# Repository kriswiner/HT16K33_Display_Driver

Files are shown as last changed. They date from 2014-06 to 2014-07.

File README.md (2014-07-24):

HT16K33_Display_Driver
======================

Simple demo of driving 4, four-digit, seven-segment [HP QDSP-6064 bubble displays](https://www.sparkfun.com/products/12710) with one [HT16K33 display driver](http://www.adafruit.com/datasheets/ht16K33v110.pdf)

Each HT16K33 cathode pin can drive two display cathodes. The HT16K33 has eight cathode pins and 16 anode pins. Therefore, the RAM Mapping HT16K33 can drive a total of 128 LED segments. So a total of four, 4-digit, 7-segment displays can be driven with this one chip with just 2 TWI wires and power and ground. That is a lot of display without taking up a lot of the GPIO pins.

I decided to try to reduce this idea of driving four bubble displays to practice; what follows is what I did and how it worked out.

First I breadboarded the circuit with Adafruit's [HT16K33 breakout board] (http://www.adafruit.com/products/1427) shown here:
 


Here is what my initial circuit looked like. The HT16K33 is powered by the 3.3 V reference from and connected to the I2C of an 8 MHz Pro Mini Arduino microcontroller.



I was able to easily get two bubble displays running from the HT16K33 breakout on my little breadboard. I actually added a third display using jumper wires to another breadboard just to prove that I really could drive four (well, at least three!) of the bubble displays at a time with just one HT16K33.

After that success, I spent most of a Saturday soldering up a circuit on a perf board with four bubble displays and one HT16K33. This is what it looks like:



Look at all those wires! This is not a great picture but you can see that all four displays are working using the display driver sketch in this repository, which currently displays floating point (top left and bottom right) or integer (top right and bottom left) numbers of four digits or less. The sketch has simple utility but is good enough to display temperature, time, and other sensor output.

The last step was biting the bullet and learning how to use Eagle CAD to design a PCB with the same circuit. It took only a few days mostly because: 1) I was able to take advantage of all the work Adafruit and [uChip](https://github.com/uChip/BubbleDisplay) had already done and, 2) I got a lot of help from Jim Lindblom of [Sparkfun] (http://www.sparkfun.com) and Dan Sheadel of [OSHPark] (http://www.oshpark.com), where I am having the first prototypes made. Here is what the boards will look like at almost actual size! (1.48 x 1.58 inches).

..........

I received the boards from OSHPark and promptly put the components on. A bad picture of the board is shown above. It was straightforward to solder even the small diode; 0805 passive components are easy to handle with a good pair of tweezers. Using a soldering iron for surface mounted components is doable but the solder joints are never going to look like machine-made parts do without a lot of practice. I noticed that the displays worked just fine mounted in their through holes before soldering; I guess there is enough contact to allow the proper current flow even without soldering. I assembled all three boards and---they all worked! I love it when this happens. This is what the boards look like in action.



The board is connected to an Arduino 3.3 V 8 MHz Pro Mini running the sketch in this repository. Notice that there are only four wires, not the rat's nest of wires from the perf board prototype. So what are the advantages of this "FrontPack" design over conventional LED display choices?  Well, 1) you don't need external current-limiting resistors with the HT16K33 chip, 2) you can run the display board wih 3.3 V or 5 V as you wish, 3) it only takes four wires to control up to 8 x 4 four-digit displays since up to eight of these "FrontPacks" can be independently addressed in a given circuit by soldering a unique 3-bit address on the board pads, 4) it has a rather small footprint at 1.48 x 1.58 inches square so it saves space, and 5) it is so retro cool!

This is the first prototype; there are several variants I can think of that might be more useful for a given application. For example, why not mount the HT16K33 on the back to make a conventional "BackPack" version of this display. This would come in handy for mounting on a cased surface. The FrontPack (I'll toss the scare quotes from now on) has the additional attribute that the bubble displays, even fully inserted into the through holes, stand proud of the top surface of the HT16K33 chip, meaning that even the FrontPack can be mounted, albeit a little more awkwardly, on an inner case surface with only the displays visible outside. But the really neat thing about the bubble displays and this through-hole mounting is that the displays can be soldered into the board at a tilt angle to aid viewing and can stand as much as a millimeter prouder still of the HT16K33 chip by a judicious choice of how far to push the displays into the board before soldering. Bottom line: even the FrontPack is likely to suit most needs.

Now there is a quirk with the current setup (there always is!). I noticed a curious unwanted behavior with this driver chip. The sketch works as intended when I have the displays numbered in (the somewhat unintuitive) order 1-2-3-4 from top right to bottom left. When I change the order to go from top left to bottom right (the more intuitive ordering), everything still works but the minus sign on displays 1 and 3 becomes intermittent. I don’t understand this behavior yet, but I suspect it has something to do with the RAM ordering of the multiplexing coupled with the particular way I am constructing the characters to display.  That is, I am hoping it is a subtle software error and not some hidden limitation of the chip. It doesn’t get in the way of using any or all of the displays, but in the interest of full disclosure, I thought I would mention this oddity. If anyone spots my error in the sketch above I would appreciate a heads up.

This is version v.01 and there are a few things I would do differently. I noticed that Adafruit (from whom I shamelessly copied the idea of using the HT16K33) used a 24 mil trace for their VDD and GND lines. This is good practice that I would follow next time but didn't here. Likewise, putting the capacitor right next to ground is OK, but it might be better to place it right next to the VDD pin on the HT16K33, instead. I used 4.7 kOhm resistors as pull-ups for the SDA and SCL lines since I am currently in the habit of using fast (400 kHz) I2C. This is in contrast to the 10 kOhm pullups used by Adafruit. I'd stick with the 4.7 kOhm in the next design iteration. Lastly, I used 39 kOhm resistors in the address lines as specified in the HT16K33 data sheet instead of the 47 kOhm resistors used by Adafruit. They probably just had a lot of these 47 kOhm resistors lying around.

I had a lot of fun designing this board, my first real experience with Eagle CAD, and I must close by thanking Adafruit for showiing me how to use this wonderful chip by Holtek, uChip from whom I shamelessly borrowed the QDSP-6064 Eagle device package and who has devised a different solution to using these retro cool bubble displays, and Sparkfun Electronics for their cheery answers to all my inane questions, and somehow providing an inexpensive supply of these quirky, odd looking, lovable bubble displays.

Despite standing on the shoulders of these giants, I take full responsibility for any and all errors in the sketch or Eagle design. I would only ask that you tell me when you find an error so I can do my best to fix it.

Update: Well I think I figured out the display ordering problem. In some sense I organized the displays backward. I think the HT16K33 prefers to roll through the RAM map sequentially and if I try to display out of order the chip has a harder time with the multiplexing. This is probably a direct result of my copying Adafruit's and uChip's schematics which were arranged for "backpack" displays, not the "frontpack" design I am using. I can still get any display or all the displays to function correctly, but it's somewhat annoying to have the top right display be number one  and then go top right to top left, then bottom right to bottom left instead of the more intuitive top left to top right, bottom left to bottom right ordering. The proper way to use this chip is to display to C0-3 A0-7, then C4-7 A0-7, then C0-3 A8-15, and finally C4-7 A8-15, I think. In any case, I took the opportunity to "fix" the design by swapping the top left bubble display with the top right one, etc., in a version 2 of the design. I also reduced the size of the board by 6% by avoiding setting traces outside, on the far side, of the bubble displays. Adafruit used 24 mil traces for their power and ground, so that's what I am using in the new design. I was using 10 mil traces everywhere else in version 1 and I maintained that in version 2. Finally, I shrunk the vias down to 15 mil diameter so I won't have gigantic holes all over the board. I ordered three boards from OSH Park and when they arrive and I assemble and test the new version, I will report the results. Here is what the new boards will look like:

....

I got the boards assembled and tested and they look pretty good! They are a little smaller than the first version, don't have that annoying display order problem, and have a slightly more rational trace pattern as well as thicker traces for power and ground. Here are a few photos:

    

The display is showing data from the BMP-180 pressure sensor. Top left is temperature in degrees Fahrenheit, top right is pressure in kiloPascals, bottom right is elevation in feet and bottom left in meters. This is a very convenient way to display numerical data. It's not as much information as can be displayed on a 16 x 2 LCD or 48 x 84 Nokia 5110 LCD display, both of which I use and love, but it only requires four wires compared to the seven or eight for the other displays. And of course, the bubble display is way retro cooler, too!

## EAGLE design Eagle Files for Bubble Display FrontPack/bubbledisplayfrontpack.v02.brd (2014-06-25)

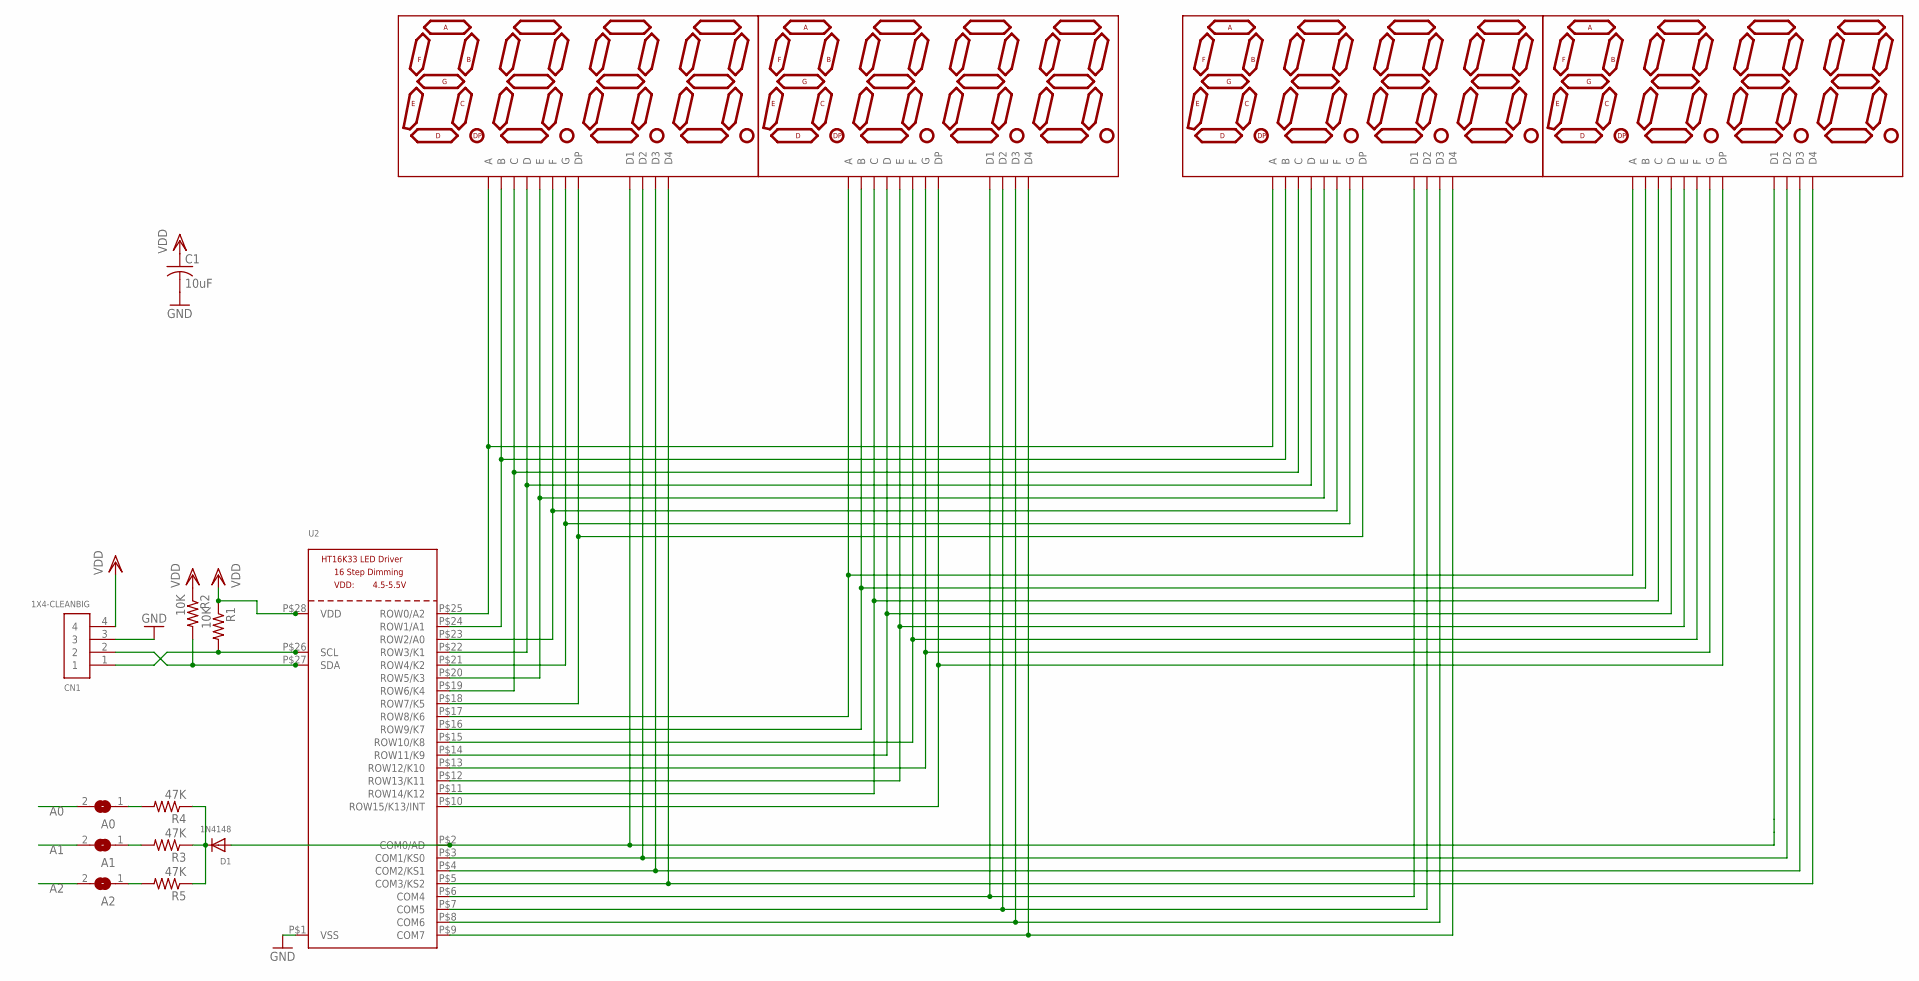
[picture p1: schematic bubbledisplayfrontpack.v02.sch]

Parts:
A0, A1, A2: SOLDERJUMPERREFLOW_NOPASTE; SOLDERJUMPER_REFLOW_NOPASTE
C1: 10uF; C0805K
CN1: 1X4-CLEANBIG; 1X04-CLEANBIG
D1: 1N4148; SOD-323F
DISPLAY1, DISPLAY2, DISPLAY3, DISPLAY4: hp; DIL12
R1, R2: 10K; R0805
R3, R4, R5: 47K; R0805
U2: HT16K33_SOP28; SOP28_300MIL

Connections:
A0: A0.2, DISPLAY1.9 (F), DISPLAY3.9 (F), U2.P$23 (ROW2/A0)
A1: A1.2, DISPLAY1.11 (B), DISPLAY3.11 (B), U2.P$24 (ROW1/A1)
A2: A2.2, DISPLAY1.12 (A), DISPLAY3.12 (A), U2.P$25 (ROW0/A2)
C0P1: D1.A, DISPLAY2.1 (D1), DISPLAY3.1 (D1), U2.P$2 (COM0/AD)
C1P10: DISPLAY2.10 (D2), DISPLAY3.10 (D2), U2.P$3 (COM1/KS0)
C2P4: DISPLAY2.4 (D3), DISPLAY3.4 (D3), U2.P$4 (COM2/KS1)
C3P6: DISPLAY2.6 (D4), DISPLAY3.6 (D4), U2.P$5 (COM3/KS2)
C4P1: DISPLAY1.1 (D1), DISPLAY4.1 (D1), U2.P$6 (COM4)
C5P10: DISPLAY1.10 (D2), DISPLAY4.10 (D2), U2.P$7 (COM5)
C6P4: DISPLAY1.4 (D3), DISPLAY4.4 (D3), U2.P$8 (COM6)
C7P6: DISPLAY1.6 (D4), DISPLAY4.6 (D4), U2.P$9 (COM7)
GND: C1.2, CN1.3, U2.P$1 (VSS)
unnamed: D1.C, R3.1, R4.1, R5.1
unnamed: DISPLAY1.8 (D), DISPLAY3.8 (D), U2.P$22 (ROW3/K1)
unnamed: DISPLAY2.9 (F), DISPLAY4.9 (F), U2.P$15 (ROW10/K8)
unnamed: A2.1, R5.2
unnamed: DISPLAY2.2 (E), DISPLAY4.2 (E), U2.P$12 (ROW13/K11)
unnamed: A1.1, R3.2
unnamed: A0.1, R4.2
SCL: CN1.1, R1.2, U2.P$26 (SCL)
SDA: CN1.2, R2.2, U2.P$27 (SDA)
SEGAD24P12: DISPLAY2.12 (A), DISPLAY4.12 (A), U2.P$17 (ROW8/K6)
SEGBD24P11: DISPLAY2.11 (B), DISPLAY4.11 (B), U2.P$16 (ROW9/K7)
SEGCP3: DISPLAY2.3 (C), DISPLAY4.3 (C), U2.P$11 (ROW14/K12)
SEGD13EP2: DISPLAY1.7 (G), DISPLAY3.7 (G), U2.P$21 (ROW4/K2)
SEGD13GP7: DISPLAY1.3 (C), DISPLAY3.3 (C), U2.P$19 (ROW6/K4)
SEGDD24P8: DISPLAY2.8 (D), DISPLAY4.8 (D), U2.P$14 (ROW11/K9)
SEGDPD13P5: DISPLAY1.5 (DP), DISPLAY3.5 (DP), U2.P$18 (ROW7/K5)
SEGDPP5: DISPLAY2.5 (DP), DISPLAY4.5 (DP), U2.P$10 (ROW15/K13/INT)
SEGED13P2: DISPLAY1.2 (E), DISPLAY3.2 (E), U2.P$20 (ROW5/K3)
SEGFP9: DISPLAY2.7 (G), DISPLAY4.7 (G), U2.P$13 (ROW12/K10)
VDD: C1.1, CN1.4, R1.1, R2.1, U2.P$28 (VDD)

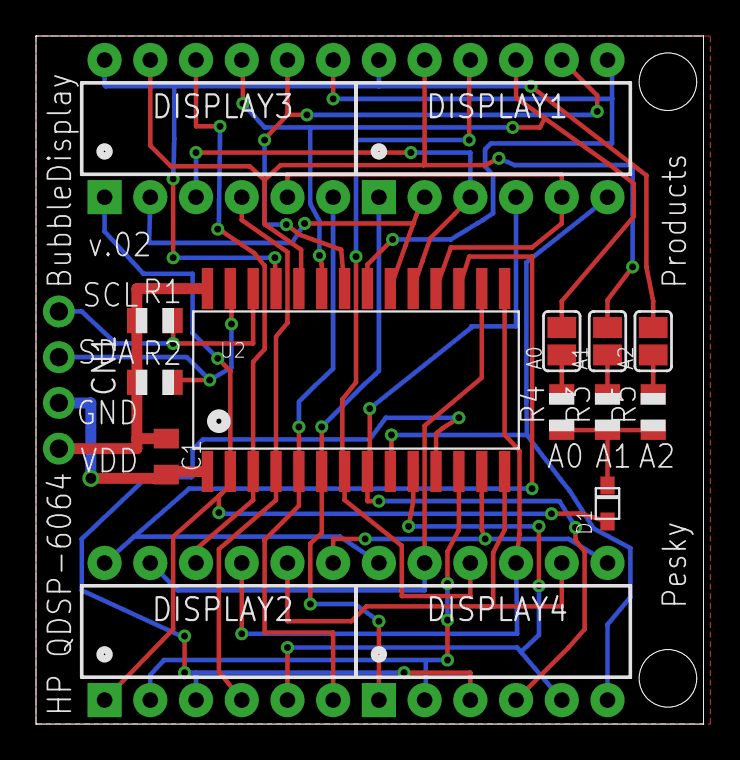
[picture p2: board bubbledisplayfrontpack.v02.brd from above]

Board: 2 copper layers, 37.1 x 38.2 mm, 16 parts (0 on the bottom side), 32 nets.

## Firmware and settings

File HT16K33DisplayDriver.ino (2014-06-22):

/* HT16K33 Display Driver Basic Example  
 by: Kris Winer
 date: May 1, 2014
 license: Beerware - Use this code however you'd like. If you 
 find it useful you can buy me a beer some time.
 
 Demonstrate basic functionality including parameterizing the register addresses, initializing the display, 
 writing integers to one or all of four seven segment LED displays.
 
 SDA and SCL should have external pull-up resistors (to 3.3V).
 10k resistors are on the HT16K33 breakout board.
 
 Hardware setup:
 HT16K33 Breakout --------- Arduino
 3.3V --------------------- 3.3V
 SDA ----------------------- A4
 SCL ----------------------- A5
 GND ---------------------- GND
 
 Note: The HT16K33 is an I2C display driver and uses the Arduino Wire library. 
 The display driver is 5V tolerant, but we are using a 3.3 V 8 MHz Pro Mini or a 3.3 V Teensy 3.1.
 We have disabled the internal pull-ups used by the Wire library in the Wire.h/twi.c utility file.
 We are also using the 400 kHz fast I2C mode by setting the TWI_FREQ  to 400000L /twi.h utility file.
 */
#include "Wire.h" 

#define HT16K33_ADDRESS         0x70
#define HT16K33_ON              0x21  // Commands
#define HT16K33_STANDBY         0x20
#define HT16K33_DISPLAYON       0x81
#define HT16K33_DISPLAYOFF      0x80
#define HT16K33_BLINKON         0x85 // Blink is off (00), 2 Hz (01), 1 Hz (10), or 0.5 Hz (11) for bits (21) 
#define HT16K33_BLINKOFF        0x81
#define HT16K33_DIM             0xE0 | 0x08 // Set dim from 0x00 (1/16th duty ccycle) to 0x0F (16/16 duty cycle)

// Arrangement for display 1 (4 digit bubble display)
// 
//               a = A0
//             _________
//            |         |
//   f = A2   |  g = A4 | b = A1
//            |_________|
//            |         |
//   e = A5   |         | c = A6
//            |_________|
//               d = A3        DP = A7

// Hookup of QDSP-6064 bubble display
//
// Display Pin          HT16K33 pin
//  1                      C0
//  2                      A5
//  3                      A6
//  4                      C2
//  5                      A7
//  6                      C3
//  7                      A4
//  8                      A3
//  9                      A2
//  10                     C1
//  11                     A1
//  12                     A0
//
// and so on... each cathode can drive two display cathodes. A total of four, 4-digit, 7-segment displays
// can be driven with this one chip with just 2 TWI wires and power and ground. That is a lot of display
// without taking up a lot of the GPIO pins.


static const byte numberTable[] =
{
  0x6F, // 0 = 0
  0x42, // 1 = 1, etc
  0x3B, // 2
  0x5B, // 3
  0x56, // 4
  0x5D, // 5
  0x7D, // 6
  0x43, // 7
  0x7F, // 8
  0x57, // 9
  0x80, // decimal point
  0x00, // blank
  0x10, // minus sign
  0x77,  // A = 13
  0x7F,  // B = 14
  0x2D,  // C = 15
  0x6F,  // D = 16
  0x3D,  // E = 17
  0x35,  // F = 18
  0x5F,  // G = 19
  0x76,   // H = 20
  0x42,   // I = 21
  0x6A,   // J = 22
  0x00,   // No K!
  0x2C,   // L = 24
  0x00,   // No M!
  0x67,   // N = 26
  0x6F,   // O = 27
  0x37,   // P = 28
  0x57,   // Q = 29
  0x77,   // R = 30
  0x5D    // S = 31
};

#define display1 1
#define display2 2
#define display3 3
#define display4 4

void setup()
{
  Wire.begin();
  Serial.begin(38400);

  initHT16K33();  // initialize display
  
  clearDsplay(display1);  // clear display 1
  clearDsplay(display2);  // clear display 2
  clearDsplay(display3);  // clear display 3
  clearDsplay(display4);  // clear display 4

  writeInteger(display1, 8888); // Test display, turn on all segments of display 1
  blinkHT16K33(2); // Blink for 2 seconds
  clearDsplay(display1);
  writeInteger(display2, 8888); // Test display, turn on all segments of display 2
  blinkHT16K33(2); // Blink for 2 seconds
  clearDsplay(display2);
  writeInteger(display3, 8888); // Test display, turn on all segments of display 3
  blinkHT16K33(2); // Blink for 2 seconds
  clearDsplay(display3);
  writeInteger(display4, 8888); // Test display, turn on all segments of display 4
  blinkHT16K33(2); // Blink for 2 seconds
  clearDsplay(display4);
  
// Test of character write; these bubble displays, like all seven-segment LED displays
// are best at displaying numbers. That doesn't mean we can't get creative and display letters also!
  writeDigit(display2, 1, 13, 0);
  writeDigit(display2, 2, 14, 0);
  writeDigit(display2, 3, 15, 0);
  writeDigit(display2, 4, 16, 0);
        
  writeDigit(display1, 1, 17, 0);
  writeDigit(display1, 2, 18, 0);
  writeDigit(display1, 3, 19, 0);
  writeDigit(display1, 4, 20, 0);  
  
  writeDigit(display4, 1, 22, 0);
  writeDigit(display4, 2, 24, 0);
  writeDigit(display4, 3, 26, 0);
  writeDigit(display4, 4, 27, 0);
        
  writeDigit(display3, 1, 28, 0);
  writeDigit(display3, 2, 29, 0);
  writeDigit(display3, 3, 30, 0);
  writeDigit(display3, 4, 31, 0);
  delay(2000);
  clearDsplay(display1);
  clearDsplay(display2);
  clearDsplay(display3);
  clearDsplay(display4);
}


void loop ()
{
   for(int j = -100; j < 100; j++) {
   writeFloat(display1, (float)(-j)/10., 1);   // write float count to display 1
   writeInteger(display2, +j);   // write integer count to display 2
   writeInteger(display3, -j);   // write integer count to display 3
   writeFloat(display4, (float)(+j)/10., 1);   // write float count to display 4
   delay(200);
   }
}

//++++++++++++++++++++++++++++++++++++++++++++++++++++++++++++++++++++++++++++++++++++++++++++++++++++++++++++++++++++++++++++
//++ Useful Functions++
//++++++++++++++++++++++++++++++++++++++++++++++++++++++++++++++++++++++++++++++++++++++++++++++++++++++++++++++++++++++++++++

void writeInteger(uint8_t dsply, int data)
{
  char string[10] = "";                             // define character array to hold the digits
  itoa(data, string);                               // get ascii character string representation of the integer to be displayed
  uint8_t length = strlen(string);                  // get the length of the string; number of digits in integer
  uint8_t blanks = 4 - length;                      // how many blanks do we have?

  if (length > 4) return;                           // if length greater than 4 digits we can't display on a four-digit display!

  for (uint8_t digit = 0; digit < blanks; digit++)  // scroll through each digit to determine what to write to the display
  {
      writeDigit(dsply, digit + 1, 11, 0);          // clear digit wherever there are blanks
  }

  for (uint8_t digit = 0; digit < 4; digit++)       // scroll through each digit to determine what to write to the display
  {
      char ch = string[digit];                      // get the ascii character of the next string segment

      if (ch == '-') {
      writeDigit(dsply, digit + 1 + blanks, 12, 0); // check if negative sign needed
      } 
      else {                                        // character must be a digit
      ch -= '0';                                    // convert it to an integer
      writeDigit(dsply, digit + 1 + blanks, ch, 0); // write it to the display; right justify the integer
      } 
  }
}

void writeFloat(uint8_t dsply, float data, uint8_t dp)
{
  char string[10] = "";  // define character array to hold the digits
  int datanew = 0;
  
  switch (dp)
  {
    case 0:
    datanew = (int )(1.*data);
    break;
 
    case 1:
    datanew = (int )(10.*data);
    break;

    case 2:
    datanew = (int )(100.*data);
    break;
 
    case 3:
    datanew = (int )(1000.*data);
    break;
   }
   
  
  itoa(datanew, string);                                    // get ascii character string representation of the integer to be displayed
  uint8_t length = strlen(string);                          // get the length of the string; number of digits in integer
  uint8_t blanks = 4 - length;                              // how many blanks do we have?

  if (length > 4) return;                                   // if length greater than 4 digits we can't display on a four-digit display!

// scroll through each digit to determine what to write to the display
for (uint8_t digit = 0; digit < blanks; digit++)            // first the blanks
  {
          if( (digit + 1) == (4 - dp) ) {                   // handle special case where blank coincides with decimal point
            writeDigit(dsply, digit + 1, 0, 0x80);          // add leading zero before decimal place
          }
          else {
            writeDigit(dsply, digit + 1, 11, 0x00);         // otherwise clear digit wherever there are blanks
          }
  }

  for (uint8_t digit = 0; digit < 4; digit++)               // now the characters to determine what to write to the display
  {
      char ch = string[digit];                              // get the ascii character of the next string segment

      if (ch == '-') {
        if((digit + 1 + blanks) == (4 - dp) ) {
          writeDigit(dsply, digit + 1 + blanks,  0, 0x80);  // check if negative sign needed, add a decimal point
          writeDigit(dsply, digit + 0 + blanks, 12, 0x00);  // add a leading zero
        }
        else {
          writeDigit(dsply, digit + 1 + blanks, 12, 0x00);  // check if negative sign needed, no decimal point
        }
        }
      else  {                                               // character must be a digit
        ch -= '0';                                          // convert it to an integer
        if((digit + 1 + blanks) == (4 - dp) ) {
          writeDigit(dsply, digit + 1 + blanks, ch, 0x80);  // write it to the display with decimal point; right justify the integer
        } 
        else {
          writeDigit(dsply, digit + 1 + blanks, ch, 0x00);  // write it to the display; right justify the integer
        } 
     }
  }
}
  

void writeDigit(uint8_t dsply, uint8_t digit, uint8_t data, uint8_t dp) 
{
if(dsply == 1) {
  digit = (digit - 1)*2 + 0; 
} 
if(dsply == 2) {
  digit = (digit - 1)*2 + 8 ;
}
if(dsply == 3) {
  digit = (digit - 1)*2 + 1;
}
if(dsply == 4) {
  digit = (digit - 1)*2 + 9;
}
writeByte(HT16K33_ADDRESS, digit, numberTable[data] | dp);
}


void clearDsplay(int dsply) 
{
  for(int i = 0; i < 8; i++)  {
  writeDigit(dsply, i, 11, 0);  // Clear display, 11 is blank in the numberTable above
  }
}


void initHT16K33()
{
  writeCommand(HT16K33_ADDRESS, HT16K33_ON);         // Turn on system oscillator
  writeCommand(HT16K33_ADDRESS, HT16K33_DISPLAYON);  // Display on
  writeCommand(HT16K33_ADDRESS, HT16K33_DIM);        // Set brightness

}


void blinkHT16K33(int time) 
{
  writeCommand(HT16K33_ADDRESS, HT16K33_BLINKON);  // Turn on blink
  delay(1000*time);
  writeCommand(HT16K33_ADDRESS, HT16K33_BLINKOFF);  // Turn on blink
}


 /* itoa:  convert n to characters in s */
 void itoa(int n, char s[])
 {
     int i, sign;
 
     if ((sign = n) < 0)  /* record sign */
         n = -n;          /* make n positive */
     i = 0;
     do {       /* generate digits in reverse order */
         s[i++] = n % 10 + '0';   /* get next digit */
     } while ((n /= 10) > 0);     /* delete it */
     if (sign < 0)
         s[i++] = '-';
     s[i] = '\0';
     reverse(s);
 } 
 
 /* reverse:  reverse string s in place */
 void reverse(char s[])
 {
     int i, j;
     char c;
 
     for (i = 0, j = strlen(s)-1; i<j; i++, j--) {
         c = s[i];
         s[i] = s[j];
         s[j] = c;
     }
 }

        // Wire.h read and write protocols
        void writeCommand(uint8_t address, uint8_t command)
  {
	Wire.beginTransmission(address);  // Initialize the Tx buffer
	Wire.write(command);              // Put command in Tx buffer
	Wire.endTransmission();           // Send the Tx buffer
}
        void writeByte(uint8_t address, uint8_t subAddress, uint8_t data)
{
	Wire.beginTransmission(address);  // Initialize the Tx buffer
	Wire.write(subAddress);           // Put slave register address in Tx buffer
	Wire.write(data);                 // Put data in Tx buffer
	Wire.endTransmission();           // Send the Tx buffer
}

        uint8_t readByte(uint8_t address, uint8_t subAddress)
{
	uint8_t data; // `data` will store the register data	 
	Wire.beginTransmission(address);         // Initialize the Tx buffer
	Wire.write(subAddress);	                 // Put slave register address in Tx buffer
	Wire.endTransmission(false);             // Send the Tx buffer, but send a restart to keep connection alive
	Wire.requestFrom(address, (uint8_t) 1);  // Read one byte from slave register address 
	data = Wire.read();                      // Fill Rx buffer with result
	return data;                             // Return data read from slave register
}

        void readBytes(uint8_t address, uint8_t subAddress, uint8_t count, uint8_t * dest)
{  
	Wire.beginTransmission(address);   // Initialize the Tx buffer
	Wire.write(subAddress);            // Put slave register address in Tx buffer
	Wire.endTransmission(false);       // Send the Tx buffer, but send a restart to keep connection alive
	uint8_t i = 0;
        Wire.requestFrom(address, count);  // Read bytes from slave register address 
	while (Wire.available()) {
        dest[i++] = Wire.read(); }         // Put read results in the Rx buffer
}

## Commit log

2014-05-09 Create HT16K33DisplayDriver
    Demonstrate basic functionality including parameterizing the register addresses, initializing the display,
    writing integers to one of four seven segment LED displays.
2014-06-22 Add Eagle files for BubbleDisplayFrontPack v.01
    First prototype of using the HT16K33 RAM Mapping 16*8 LED Driver to
    display to 4 four-digit, eight-segment QDSP-6064 bubble displays.
    [bubbledisplaybackpack.v01.osh.brd, bubbledisplaybackpack.v01.sch]
2014-06-22 BubbleDisplayFrontPackDesign.v01
    HT16K33 RAM Mapping 16*8 LED Driver with 4 four-digit, eight-segment
    QDSP-6064 bubble displays in a "frontpack" board design
    [bubbledisplaybackpack.v01.osh.brd, bubbledisplayfrontpack.v01.brd, bubbledisplayfrontpack.v01.sch]
2014-06-25 Added BubbleDisplayFrontpack.v02 Eagle files
    [bubbledisplayfrontpack.v02.brd, bubbledisplayfrontpack.v02.sch]

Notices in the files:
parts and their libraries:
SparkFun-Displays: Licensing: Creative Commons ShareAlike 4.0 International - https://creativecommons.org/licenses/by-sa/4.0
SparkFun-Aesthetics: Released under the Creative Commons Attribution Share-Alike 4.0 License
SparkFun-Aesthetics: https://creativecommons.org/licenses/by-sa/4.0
